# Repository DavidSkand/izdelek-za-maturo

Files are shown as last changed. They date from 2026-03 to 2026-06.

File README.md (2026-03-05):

# Projekt: Zaznavanje AprilTagov s kamero







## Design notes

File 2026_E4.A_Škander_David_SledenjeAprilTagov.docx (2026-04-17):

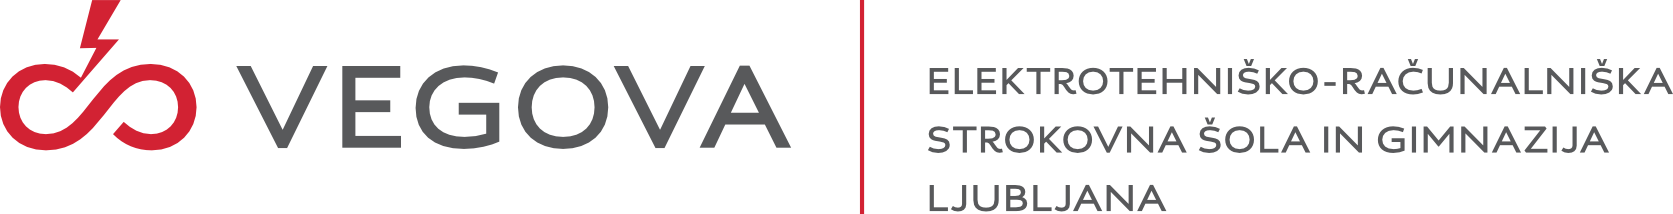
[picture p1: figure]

Lasersko sledenje AprilTag oznak

Strokovno poročilo

Mentor: David Zindović, prof. Avtor: David Škander, E 4. A

Ljubljana, april 2026

Povzetek

V sklopu strokovnega poročila je opisan razvoj laserskega sledilnega sistema, ki z uporabo računalniškega vida v realnem času zaznava oznake AprilTag in nanje usmeri laserski žarek. Sistem sestavljajo 3D-natisnjen nagibno-zasučni (pan-tilt) mehanizem, ki je bil v celoti zmodeliran v programu Fusion 360, dva servo motorja MG90S za krmiljenje gibanja, spletna kamera Logitech C920-C za zajem videa ter mikrokrmilnik Arduino Uno kot vmesnik med programsko in strojno opremo. Programski del sestavljata dve komponenti: skripta v jeziku Python, ki s pomočjo knjižnic OpenCV in pyapriltags zajema video, prepoznava oznake AprilTag, izračuna njihove koordinate v vidnem polju kamere in jih prek serijske povezave posreduje mikrokrmilniku, ter koda za Arduino, ki prejete koordinate pretvori v ustrezne kote servo motorjev z dodanim algoritmom glajenja premikov za tekoče sledenje. Projekt je bil uspešno realiziran in deluje v realnem času, med možnimi nadgradnjami pa sta izpostavljena implementacija PID-regulacije ter razširitev sistema na prepoznavanje obrazov in poljubnih premikajočih se objektov.

Ključne besede:

AprilTag, lasersko sledenje, nagibno-zasučni mehanizem, računalniški vid, OpenCV, Arduino Uno, servo motor, 3D tisk, Fusion 360, Python

Abstract

This report describes the development of a laser tracking system that uses computer vision to detect AprilTag markers in real time and direct a laser beam toward them. The system consists of a 3D-printed pan-tilt mechanism modelled in Fusion 360, two MG90S servo motors, a Logitech C920-C webcam and an Arduino Uno microcontroller. The software comprises a Python script using OpenCV and pyapriltags to detect markers and transmit their coordinates to the Arduino via serial communication, and Arduino code that converts the coordinates into servo angles with a smoothing algorithm for fluid motion. The project was successfully completed and operates in real time; potential upgrades include PID control and recognition of faces or arbitrary moving objects.

Keywords:

AprilTag, laser tracking, pan-tilt mechanism, computer vision, OpenCV, Arduino Uno, servo motor, 3D printing, Fusion 360, Python

## 1. UVOD

Misel o tem projektu se je rodila ob opazovanju sodobnih avtomatiziranih sistemov, kjer stroji z neverjetno hitrostjo opravljajo naloge, ki so za človeško oko skoraj neulovljive. Vedno me je navdušilo, kako lahko računalnik sploh vidi in razume, kaj se dogaja okoli njega in nato na podlagi teh podatkov krmili gibanje mehanizma. Izvedel sem, da se vrobotiki oznake AprilTag najpogosteje uporabljajo kot zanesljive referenčne točke za kalibracijo kamer in natančno določanje položaja v prostoru. Čeprav so na prvi pogled le nekakšni črno-beli kvadratki, nosijo v sebi podatke podobno kot QR-kode, vendar so zaradi manjše količine informacij bistveno hitrejše in bolj uporabne za sledenje.

Na podlagi tega sem se odločil, da to hitrost in natančnost uprizorim sam. Izdelal sem nagibno-zasučni laserski sistem (angl. pan-tilt), ki prek kamere in algoritmov prepozna oznako AprilTag v prostoru. Sistem nato podatke posreduje servo motorjema, ki ustrezno premakneta sklepe mehanizma in laserski žarek natančno usmerita v tarčo.

## 2. IZVEDBA PROJEKTA

### 2.1 Modeliranje in 3D tisk pan-tilt mehanizma

Ob začetku projekta nisem točno vedel, na kakšen način bi izvedel premikanje laserja, saj obstaja veliko različnih možnosti. Ugotovil sem, da se za takšne namene najpogosteje uporablja nagibno-zasučni (pan-tilt) sistem. Ta deluje tako, da zasučni del mehanizma (angl. pan) s pomočjo prvega servo motorja izvaja rotacijo okoli navpične osi, s čimer laserski žarek pomika po vodoravni ravnini (x-os). Nagibni del mehanizma (angl. tilt) pa z drugim motorjem omogoča rotacijo okoli vodoravne osi, kar žarek usmerja po navpični ravnini (y-os). Kljub temu da na spletu že obstaja veliko vnaprej pripravljenih 3D modelov, sem se odločil, da bom celoten sistem zmodeliral sam v programu Fusion 360. S tem sem želel pridobiti novo znanje modeliranja in se naučiti uporabljati omenjeni program.

Po analizi več primerov sem se odločil, da bom sistem ustvaril v treh različnih delih. Najprej sem začel z modeliranjem spodnjega dela, zasučnega (pan) mehanizma
(Slika 1). Začel sem z risanjem ravne podlage (oznaka 1), v katero sem v vsakem kotu postavil luknje za pritrdilne vijake (oznaka 2). Na sredino podlage sem nato zmodeliral namensko ohišje za prvi servo motor (oznaka 3), v katerem sem predvidel tudi ustrezen izrez za nemoten prehod priključnega kabla (oznaka 4).

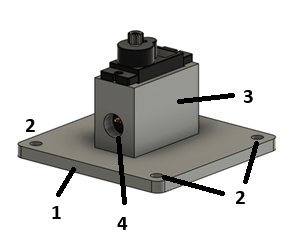
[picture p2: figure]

Slika 1: Model zasučnega mehanizma

Nato sem se lotil drugega dela, imenovanega U-kotnik, ki služi kot povezovalni člen med zasučnim in nagibnim (pan-tilt) mehanizmom (Slika 2). Ta model mi je vzel bistveno več časa in predstavljal večji izziv. Lotil sem se ga podobno kot prvega: najprej sem oblikoval ravno podlago (oznaka 1), nato pa ob straneh dodal vertikalni stojali (oznaka 2), ki podpirata zgornji del mehanizma. Na sredini podlage sem naredil glavno odprtino za pritrditev servo ročice na spodnji motor (oznaka 3), ob kateri so še manjše luknje za vijake, s katerimi se ročica čvrsto spoji s podlago. Na enem izmed stojal sem nato izdelal natančno priležno odprtino v obliki servo ročice (oznaka 4) ter dodal potrebne pritrdilne luknje. Tako se zgornji (tilt) servo motor prek ročice trdno privije neposredno na stojalo U-kotnika, s čimer sta oba mehanizma zanesljivo združena.

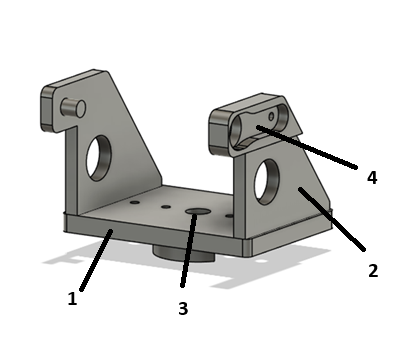
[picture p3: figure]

Slika 2: Model U-kotnika

Nazadnje sem zmodeliral še zgornji, nagibni (tilt) del sistema (Slika 3). Tudi pri tem delu sem začel z osnovno ploščo (oznaka 1), na kateri sem oblikoval ohišje za laser v obliki kvadra (oznaka 2). V ta kvader sem izrezal natančno odprtino, ki služi tesnemu prileganju in fiksiranju laserja (oznaka 3). Na spodnji strani plošče sem nato izdelal nosilna stebrička (oznaka 4) z odprtinami, ki sta prilagojeni za čvrsto pritrditev na zgornji servo motor. S tem sem zagotovil, da se celoten zgornji sklop skupaj z laserjem nemoteno nagiba okoli vodoravne osi.

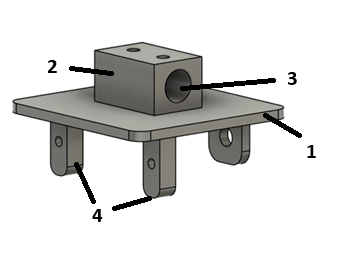
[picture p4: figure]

Slika 3: Model nagibnega mehanizma

In sedaj če sestavimo vse skupaj izgleda takole:

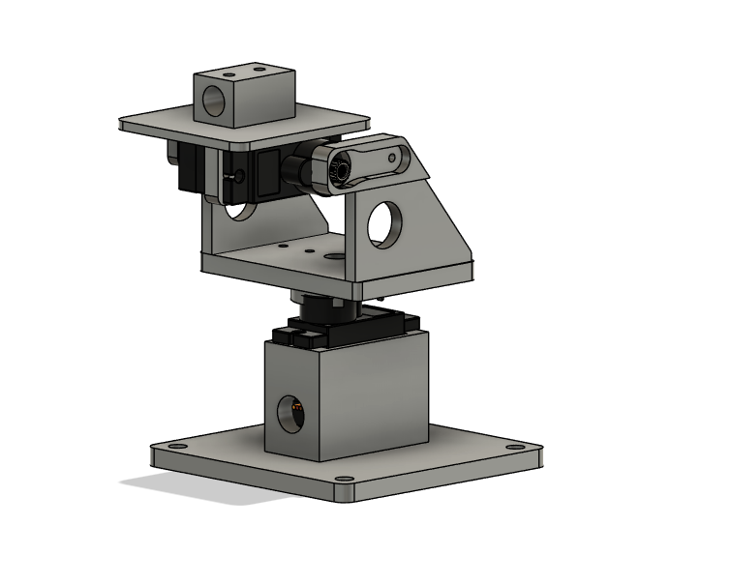
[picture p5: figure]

Slika 4: Sestavljen model nagibno-zasučnega sistema

### 2.2 Električne komponente in vezava

#### 2.2.1 Servo motor MG90S

Za premikanje obeh osi pan-tilt mehanizma sem izbral dva servo motorja MG90S. Odločitev za ta model je temeljila na njegovi sestavi, saj ima vgrajen kovinski prenos (zobnike), medtem ko ima osnovni model SG90 plastičnega. To motorjema omogoča doseganje večjega navora in zagotavlja večjo stabilnost pri prenašanju teže.

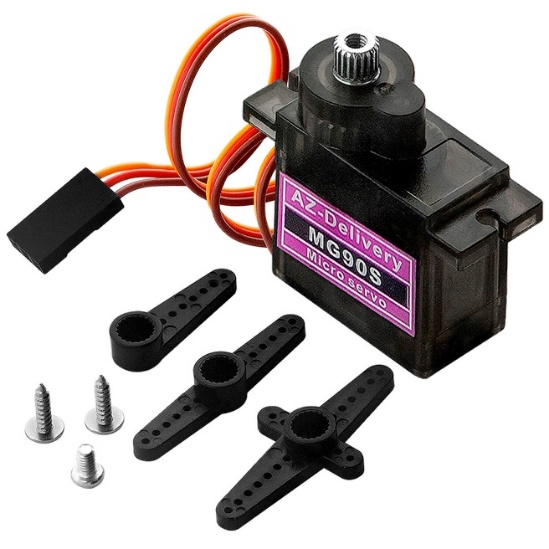
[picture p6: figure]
MG90S micro servo engine compatible with Arduino

Slika 5: Servo motor MG90S

#### 2.2.2 Mikrokrmilnik Arduino Uno

Za krmiljenje servo motorjev sem v sistem vključil mikrokrmilnik Arduino Uno, ki služi kot vmesnik med osebnim računalnikom in mehanskimi deli naprave. Ker servo motorji za natančno pozicioniranje potrebujejo ustrezen signal, sem za njihovo krmiljenje uporabil digitalne pine, ki podpirajo PWM (pulzno-širinsko modulacijo). Komunikacija z računalnikom in nalaganje programske opreme pa potekata neposredno preko USB vmesnika.

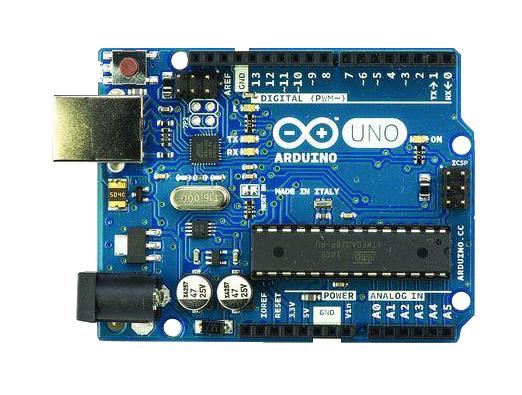
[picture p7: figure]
K010007 ARDUINO, Starter Kit, Arduino UNO, Projects Book | Farnell Slovenija

Slika 6: Mikrokrmilnik Arduino Uno

#### 2.2.3 Spletna kamera Logitech C920-C

Za zaznavanje oznak AprilTag sem uporabil spletno kamero Logitech C920-C. Kamera je fiksno nameščena tako, da ima neoviran pogled in s svojim zornim kotom v celoti pokriva območje, znotraj katerega se nahajajo tarče. Njena naloga je pošiljanje video signala na računalnik, kjer namenska skripta v jeziku Python video najprej zajame in pretvori v posamezne slike, jih obdela ter nato v njih s pomočjo algoritma poišče točne koordinate oznak.

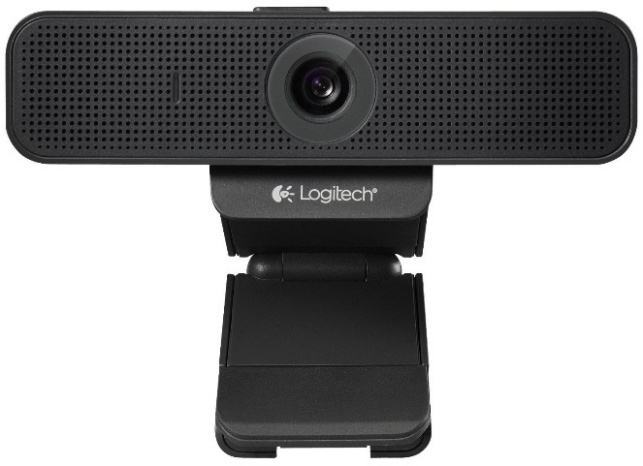
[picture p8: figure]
Logitech C920-C Webcam (Business Product) with 1080p HD Video Certified for Cisco Jabber : Amazon.ca: Electronics

Slika 7: Spletna kamera Logitech C920-C

#### 2.2.4 Laserska dioda

Kot vizualni indikator sledenja sem uporabil mini lasersko diodo z rdečim žarkom valovne dolžine 650 nm. Modul deluje pri napetosti 5 V z izhodno močjo 5 mW, kar pomeni, da se dobro vidi tudi pri dnevni svetlobi in hkrati spada v varen razred laserjev. Laserski modul je nameščen na zgornjem (tilt) delu 3D-natisnjenega mehanizma, tako da se žarek premika skupaj z motorjema in kaže na zaznano oznako.

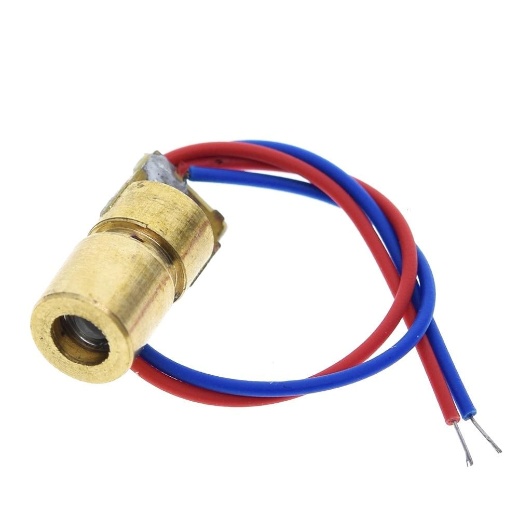
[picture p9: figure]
Adafruit 5mw Laser Diode 650nm 5mW Red Dot Laser Module – Focusable, 12x55mm, 5V Powered, Long Working Life For Positioning & Marking Adafruit Laser Diode 650nm

Slika 8: Modul laserja

#### 2.2.5 Arduino Sensor Shield v5 in napajanje

Za boljši izgled in preglednost sem uporabil razširitveno ploščo Arduino Sensor Shield v5. Ta omogoča preprosto povezovanje večjega števila komponent in modulov brez nepotrebnega prepletanja žic. Ker servo motorji ob delovanju porabijo precej električnega toka, bi njihovo neposredno napajanje preko mikrokrmilnika Arduino lahko povzročilo pregrevanje ali nestabilno delovanje. Da bi to preprečil, sistem napajam z zunanjim 5 V napajalnikom z izhodnim tokom 2 A. To zagotavlja dovolj moči za delovanje obeh motorjev in laserja, hkrati pa ščiti mikrokrmilnik pred preobremenitvijo.

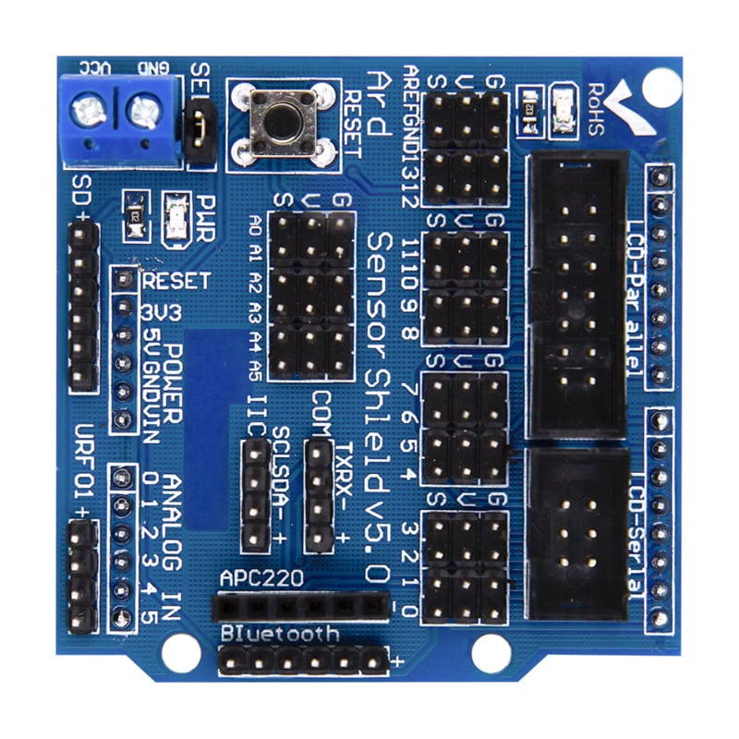
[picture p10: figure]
Sensor Shield v5.0 for Arduino UNO R3 - OTRONIC

Slika 9: Arduino Sensor Shield v5

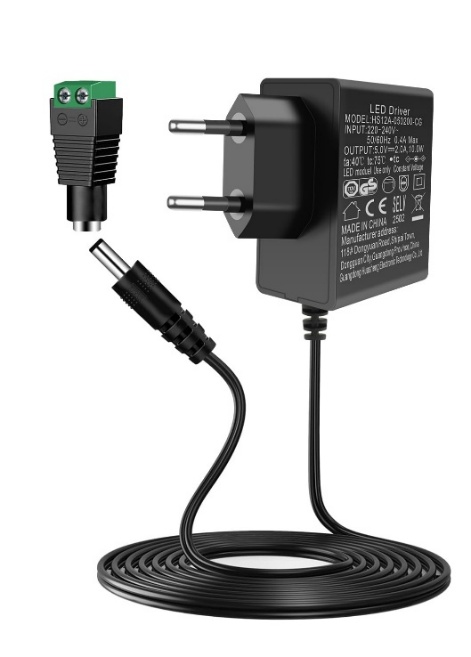
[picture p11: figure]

Slika 10: Napajalnik 5V 2A

#### 2.2.6 Električna vezava

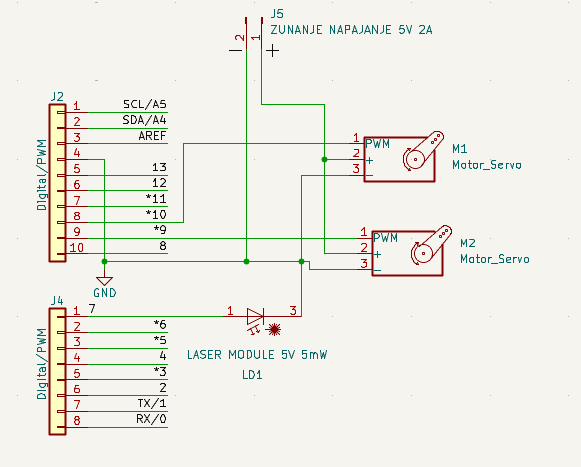
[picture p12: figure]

Slika 11: Električna vezava sistema

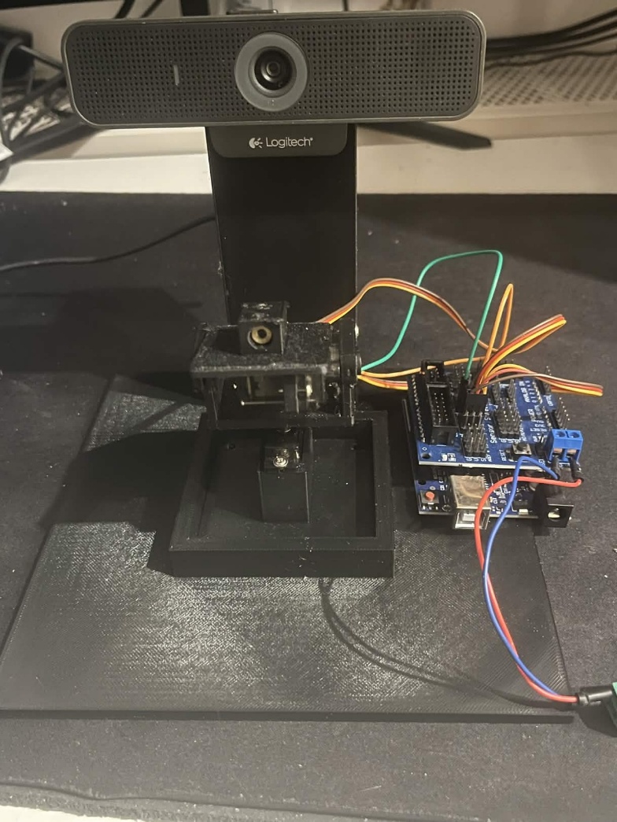
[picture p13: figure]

Slika 12: Sestavljen izdelek

### 2.3 Program

#### 2.3.1 Python skripta

Pri programskem delu sem se podrobneje poglobil v delovanje knjižnice OpenCV. Razvoj Python skripte sem izvedel postopoma: najprej sem implementiral zajem slike s kamere in zaznavanje oznak AprilTag. Zatem sem kodo nadgradil z algoritmom za izračun njihovih koordinat, v zadnjem koraku pa sem dodal še serijsko komunikacijo za pošiljanje teh podatkov mikrokrmilniku Arduino.

Slika 13: Izsek kode z uvozom knjižnic

Na začetku programske kode sem uvozil vse potrebne knjižnice (Slika 13). Za zajem in obdelavo videa sem uporabil knjižnico cv2 (OpenCV), za prepoznavanje oznak AprilTag pa namensko knjižnico pyapriltags. Knjižnico time sem potreboval za izračun in prikaz sličic na sekundo (FPS) ter za natančno časovno krmiljenje pošiljanja podatkov (omejitev na 33 Hz). Knjižnica serial pa skrbi za serijsko komunikacijo, ki sem jo uporabil za prenos izračunanih koordinat med Python kodo in mikrokrmilnikom Arduino.

Slika 14: Izsek kode za Inicializacijo kamere in serijske komunikacije.

V uvodnem delu programa (Slika 14) sem inicializiral zajem videa in komunikacijski vmesnik. S funkcijo cv2.VideoCapture(1) sem aktiviral spletno kamero. Nato sem s funkcijo serial.Serial iz knjižnice serial vzpostavil serijsko povezavo z mikrokrmilnikom Arduino preko vrat COM6. Hitrost prenosa sem nastavil na 115200 baudov, kar se mora ujemati z nastavitvami v Arduino kodi. Na koncu sem uporabil ukaz time.sleep(2), ki za dve sekundi začasno ustavi izvajanje skripte. Ta zamik je nujen za zanesljivo sinhronizacijo komunikacije med napravama, saj se ob odprtju serijskih vrat mikrokrmilnik samodejno ponovno zažene in potrebuje kratek čas, preden je pripravljen na sprejemanje podatkov.

Slika 15: Izsek kode z določitvijo spremenljivk in pogojev za pošiljanje.

V tem delu programske kode (Slika 15) sem definiral glavne parametre za obnašanje sistema. Z ukazom Detector() sem inicializiral iskalnik, ki na sliki prepozna oznake AprilTag. Začetni koordinati sta nastavljeni na 320 in 240, kar pri izbrani ločljivosti 480p (640x480) predstavlja natančno sredino vidnega polja kamere. Koordinate se mikrokrmilniku pošiljajo na vsake 0,03 sekunde, pri čemer se zadnje poslane vrednosti takoj shranijo v spremenljivki last_sent_x in last_sent_y. Na ta način program sproti preverja, za koliko pikslov se je oznaka dejansko premaknila. Če je ta premik manjši ali enak dvema piksloma, sistem novih koordinat ne pošlje.

Slika 16: Izsek kode za obdelavo slike in detekcijo oznak AprilTag.

V tem koraku (Slika 16) sem s funkcijo cv2.cvtColor zajeto sliko pretvoril v odtenke sive barve. Barvne slike so v knjižnici OpenCV standardno zapisane v formatu BGR, kar pomeni, da so sestavljene iz treh barvnih kanalov (modrega, zelenega in rdečega). S pretvorbo v sivinsko sliko sistem obdrži le en kanal, kar znatno zmanjša količino podatkov in pohitri obdelavo. Poleg tega knjižnica pyapriltags za svoje delovanje izrecno zahteva sivinsko sliko, saj barve pri prepoznavanju niso pomembne, temveč algoritem išče zgolj ostre kontraste med črnimi in belimi segmenti oznake. Primer pretvorbe je prikazan na spodnji sliki (Slika 16).

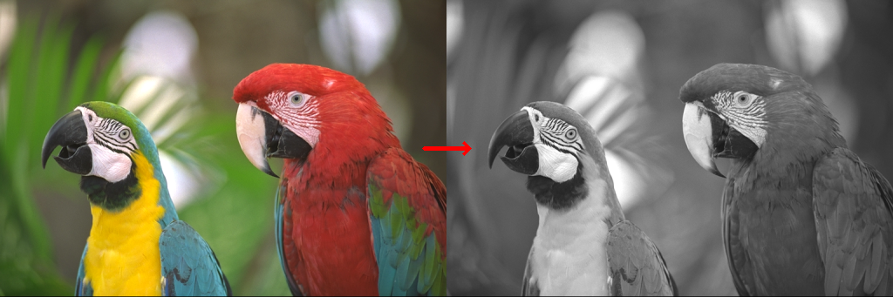
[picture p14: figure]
OpenCV.ImgProc.MiscImgTransform

Slika 17: Pretvorba iz BGR v sivinsko sliko

Vrstica kode tags = at_detector.detect(gray) izvede dejansko prepoznavanje in izolacijo oznak AprilTag na sliki. Detektor v tem koraku analizira sivinsko sliko in v spremenljivko tags shrani vse ugotovljene podatke o najdenih oznakah. Če kamera ne zazna nobene oznake, ostane ta seznam prazen. Ob uspešni detekciji pa program pridobi vse potrebne informacije (od identifikacijske številke (ID) do koordinat središča in vseh štirih oglišč oznake.

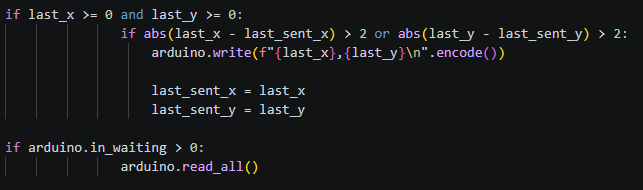
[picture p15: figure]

Slika 18: Izsek kode, ki preveri velikost premika značilke in pošlje podatke na Arduino.

Tukaj (Slika 18) se koordinate dejansko pošljejo na Arduino v formatu X,Y. Pred pošiljanjem se preveri veljavnost koordinat (last_x >= 0), ker če kamera ne zazna oznake vrednosti padejo na -1, kar bi povzročilo da laser skoči na napačno pozicijo. Na koncu se še počisti vhodni buffer Arduino krmilnika z read_all(), da se podatki ne kopičijo in povzročajo zamika.

Slika 19: Izsek kode, ki vizualno prikaže delovanje.

Za lažji pregled sem na okno kamere dodal vizualne indikatorje (Slika 19). S funkcijo cv2.rectangle program nariše moder okvir okoli zaznane značilke Apriltag, s funkcijo cv2.putText pa se pod njim izpiše njegov ID in koordinate. Tako lahko sproti vidim ali sistem pravilno zaznava oznako in kje na sliki se nahaja. Slika 20 pa prikazuje kako izgledae zaznavanje oznak in kako laser pokaže nanjo.

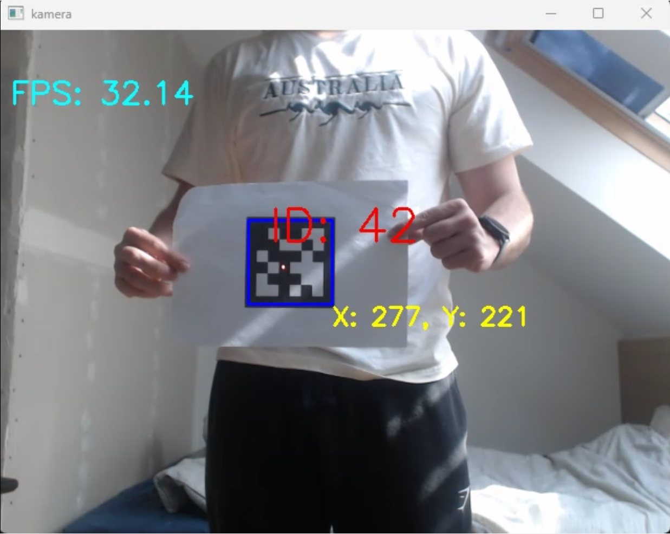
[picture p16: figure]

Slika 20: Prikaz zaznavanja oznak Apriltag

#### 2.3.2 Arduino koda

Naslednji sklop programske opreme predstavlja koda za mikrokrmilnik Arduino, ki deluje kot sprejemnik podatkov in skrbi za ustrezno premikanje zasučnega in nagibnega mehanizma.

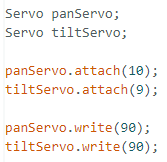
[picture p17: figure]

Slika 21: Izsek kode za deklaracijo in inicializacijo obeh servo motorjev.

Pred samo nastavitvijo pinov sem moral v kodi najprej deklarirati ustrezna objekta za oba motorja (s pomočjo vključene knjižnice Servo.h) (Slika 21). Nato sem s funkcijo attach() vsakemu objektu dodelil ustrezen priključni pin, pin 10 za zasučni in pin 9 za nagibni mehanizem. Oba izbrana pina podpirata pulzno-širinsko modulacijo (PWM), kar je nujno za krmiljenje servo motorjev. S klicem funkcije write(90) pa sem zagotovil, da se oba servota ob zagonu vedno premakneta na sredino, torej na 90 stopinj.

Slika 22: Izsek kode za preslikavo slikovnih koordinat (pikslov) v ciljne kote servo motorjev.

Ko Arduino prejme koordinate s strani računalnika, jih je potrebno pretvoriti v dejanske kote servo motorjev. To naredi funkcija floatMap() (Slika 22), ki X koordinato (0-640) pretvori v kot pan servoja, Y koordinato (0-480) pa v kot tilt servoja. Dodan je še pan_offset in tilt_offset za kalibracijo, ker laser ni nameščen točno na osi kamere.

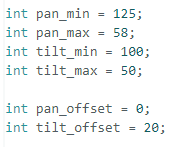
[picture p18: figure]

Slika 23: Izsek kode z definicijo mejnih kotov in začetnih odmikov za servo motorje

Na Sliki 23 spremenljivke določajo kalibracijo sistema. pan_min in pan_max določata kote servoja, ki ustrezata levemu in desnemu robu kamere — torej ko je oznaka na levem robu slike (X=0) se pan servo premakne na 125°, ko je na desnem robu (X=640) pa na 58°. Enako velja za tilt_min in tilt_max samo za Y os. tilt_offset = 20 pa je korekcija ker laser ni nameščen točno na osi kamere, kar povzroči da brez offseta laser ne kaže točno na oznako.

Slika 24: Izsek kode z algoritmom za bolj tekoče sledenje zaznani tarči.

Da pa se servo ne bi sunkovito premaknil neposredno na ciljno pozicijo, sem dodal glajenje (angl. smoothing) (Slika 24). Vrednost smoothing = 0.15 pomeni da se vsak korak premakne 15% proti cilju in ohrani 85% trenutne pozicije. Rezultat je gladko, postopno premikanje namesto nenadnih skokov, kar zmanjša obrabo servo motorjev in izboljša videz sledenja.

Slika 25: Izsek kode za varnostno omejevanje kotov

Servo motorji sicer omogočajo premik do 180 stopinj, vendar sem njun kot omejil med 10° in 170° s funkcijo constrain() (Slika 25). Da se motorja ne bi zadela ob fizične meje mehanizma in se tako poškodovala. Funkcija write() pa dejanski kot pošlje servoju kot PWM signal.

## 3. ZAKLJUČEK

Cilj projekta je bil izdelati laserski sledilni sistem, ki v realnem času zaznava oznake AprilTag in nanje usmeri laserski žarek prek nagibno-zasučnega mehanizma. Sistem je bil uspešno realiziran, kamera zaznava oznake, Python skripta izračuna njihove koordinate in jih posreduje mikrokrmilniku Arduino, ki ustrezno krmili oba servo motorja. Med izdelavo sem naletel na več praktičnih izzivov. Pri 3D tisku so bile mere nekaterih delov nepravilne, kar je povzročilo težave pri montaži: luknje za vijake so bile premajhne in nekateri deli so se zadevali ob stene ohišij, zato je bilo treba modele v programu Fusion 360 večkrat popraviti in dele natisniti znova. Zahtevna je bila tudi kalibracija sistema, saj laserski modul ni nameščen točno na osi kamere, kar povzroči sistematičen odmik žarka od središča zaznane oznake. Odmik sem delno odpravil z ročno nastavljenimi korekcijskimi vrednostmi v kodi, vendar popolne natančnosti ni mogoče doseči brez mehanske poravnave. Dodatno omejitev predstavlja tudi konstrukcijska zasnova, pri kateri celoten zgornji sklop sloni zgolj na prvem servo motorju brez dodatnih opor, kar pri hitrejših premikih zmanjša stabilnost sistema. Kljub tem izzivom projekt deluje v skladu z zastavljenimi cilji in predstavlja dobro osnovo za nadaljnji razvoj.

## 4. VIRI IN LITERATURA

OpenCV dokumentacija. 2026. OpenCV Tutorials. Dostopno prek: https://docs.opencv.org/4.13.0/d9/df8/tutorial_root.html (5. 1. 2026).

WillB97. 2026. pyapriltags. Dostopno prek:
https://github.com/WillB97/pyapriltags (18. 1. 2026).

AprilRobotics. 2026. apriltag. Dostopno prek:
https://github.com/AprilRobotics/apriltag (18. 1. 2026).

Arduino. 2026. Servo Motors with Arduino. Dostopno prek: https://docs.arduino.cc/learn/electronics/servo-motors/ (25. 1. 2026).

Bit-CCTV. 2025. What is Pan-Tilt. Dostopno prek:
https://www.bit-cctv.com/what-is-pan-tilt.html (22. 12. 2025).

GeeksforGeeks. 2026. OpenCV Python Tutorial. Dostopno prek: https://www.geeksforgeeks.org/python/opencv-python-tutorial/ (5. 1. 2026).

Alldatasheet. 2026. MG90S Datasheet. Dostopno prek: https://www.alldatasheet.com/datasheet-pdf/pdf/1132104/ETC2/MG90S.html (2. 2. 2026).

Arduino Forum. 2026. Arduino Sensor Shield v5. Dostopno prek: https://forum.arduino.cc/t/arduino-sensor-shield-v5-apc220-manual/223457 (15. 3. 2026).

Printables. 2025. 3D modeli. Dostopno prek:
https://www.printables.com/model/1069760-9g-servo-pan-tilt-system (22. 12. 2025).

Autodesk. 2025. Fusion 360. Dostopno prek:

https://www.autodesk.com/learn/ondemand/curated/introduction-to-fusion (22. 12. 2025).

IZJAVA O AVTORSTVU

Izjavljam, da je strokovno poročilo Lasersko sledenje AprilTag oznak v celoti moje avtorsko delo, ki sem ga izdelal samostojno s pomočjo navedene literature in pod vodstvom mentorja.

Datum: 17. 4. 2026

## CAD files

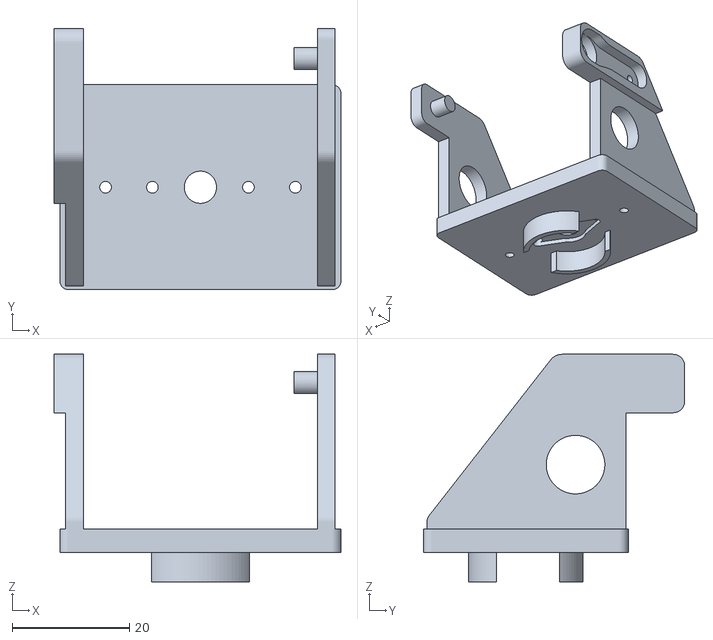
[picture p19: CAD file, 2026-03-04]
3d_design/ubracket.stl
49.0 x 44.6 x 38.8

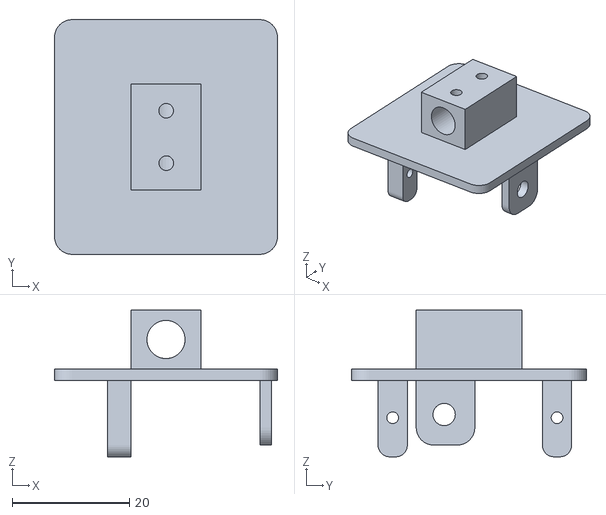
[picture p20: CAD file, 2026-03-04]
3d_design/tilt.stl
38.0 x 40.0 x 25.0

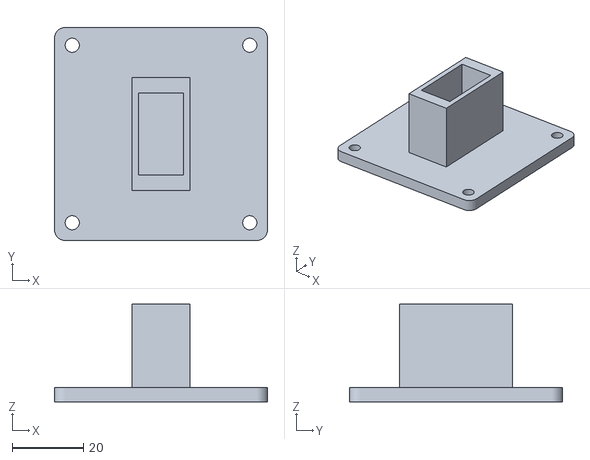
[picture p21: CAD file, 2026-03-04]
3d_design/base.stl
60.0 x 60.0 x 27.5

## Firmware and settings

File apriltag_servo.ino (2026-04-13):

#include <Servo.h>

Servo panServo;  // Pan os (X) na pinu 9
Servo tiltServo; // Tilt os (Y) na pinu 10

const int laserPin = 7;

// Spremenljivke za pozicijo
float currentPan = 90.0;
float currentTilt = 90.0;
float targetPan = 90.0;
float targetTilt = 90.0;

// Shranjevanje zadnjih koordinat za mrtvo območje
int last_x_pixel = 320;
int last_y_pixel = 240;

// Kalibracija - prilagodi glede na tvojo nastavitev
int pan_min = 125;   // Kot ko je X = 0
int pan_max = 58;    // Kot ko je X = 640
int tilt_min = 100; 
int tilt_max = 50;

// Mrtvo območje (Deadband) - število pikslov, ki jih ignoriramo
int deadband = 4; 

int pan_offset = 0;   // tune this: + moves laser right, - moves left
int tilt_offset = 20;  // tune this: + moves laser down, - moves up

// Glajenje premikanja (Smoothing)
float smoothing = 0.15; 
unsigned long lastSmoothUpdate = 0;
const unsigned long smoothInterval = 20; // Posodobitev na 20ms (50 Hz)

// Funkcija za preračun pikslov v kote
float floatMap(float x, float inMin, float inMax, float outMin, float outMax) {
  return (x - inMin) * (outMax - outMin) / (inMax - inMin) + outMin;
}

void setup() {
  Serial.begin(115200);
  Serial.setTimeout(5); // Hitra odzivnost serijske povezave
  
  panServo.attach(10);
  tiltServo.attach(9);
  
  // Postavi servomotorje na sredino ob zagonu
  panServo.write(90);
  tiltServo.write(90);

  pinMode(laserPin, OUTPUT);
  digitalWrite(laserPin, HIGH);
}

void loop() {
  // Preveri, če so prišli novi podatki iz računalnika
  if (Serial.available() > 0) {
    String data = Serial.readStringUntil('\n');
    data.trim();
    
    int commaIndex = data.indexOf(',');
    
    // Preveri, če je prejeti niz pravilen
    if (commaIndex > 0) {
      int x_pixel = data.substring(0, commaIndex).toInt();
      int y_pixel = data.substring(commaIndex + 1).toInt();

      // Mrtvo območje: posodobi cilj le, če je premik večji od deadband-a
      if (abs(x_pixel - last_x_pixel) > deadband || abs(y_pixel - last_y_pixel) > deadband) {
        
        // Izračunaj nove ciljne kote
        targetPan  = floatMap(x_pixel, 0, 640, pan_min, pan_max)  + pan_offset;
        targetTilt = floatMap(y_pixel, 0, 480, tilt_min, tilt_max) + tilt_offset;
        
        // Shrani zadnje piksle
        last_x_pixel = x_pixel;
        last_y_pixel = y_pixel;
      }
    }
  }

  // Glajenje in premikanje servomotorjev neodvisno od hitrosti Seriala
  unsigned long now = millis();
  if (now - lastSmoothUpdate >= smoothInterval) {
    lastSmoothUpdate = now;

    // Postopno premikanje proti cilju (Smoothing)
    currentPan = (targetPan * smoothing) + (currentPan * (1.0 - smoothing));
    currentTilt = (targetTilt * smoothing) + (currentTilt * (1.0 - smoothing));



    // Premik servomotorjev z varnostno omejitvijo
    panServo.write((int)constrain(currentPan, 10, 170));
    tiltServo.write((int)constrain(currentTilt, 10, 170));
  }
}

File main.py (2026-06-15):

import cv2
from pyapriltags import Detector
import time
import serial

camera = cv2.VideoCapture(0) 

at_detector = Detector()

start_time = time.time()  # Start the timer

arduino = serial.Serial(port='COM3',   baudrate=115200, timeout=.1)

last_x, last_y = 320, 240

last_seen = time.time()

timeout = 0.5 

last_sent_x = -1
last_sent_y = -1

time.sleep(2)  
last_send = 0
send_period = 0.03  # 33 Hz

#preveri če kamera deluje
if not camera.isOpened():  
    print('cannot open camera')
    exit()


while(camera.isOpened()):
    ret, frame = camera.read()       #pridobi ret, Width,Height
    if ret == False:    
        print('something went wrong')
        break
      

    if ret == True:
        gray = cv2.cvtColor(frame, cv2.COLOR_BGR2GRAY)  
        tags = at_detector.detect(gray)   #lista tagsx
        now = time.time()

        if len(tags) > 0:
            # choose one tag (first one)
            tag = tags[0]
            center = tag.center
            last_x, last_y = int(center[0]), int(center[1])


        #vzame listo in kliče vsak tag posebaj
        for tag in tags: 
            center = tag.center
            tagid = tag.tag_id
            width, height = 80, 80
            top_left = (int(center[0] - width/2), int(center[1] - height/2))
            bottom_right = (int(center[0] + width/2), int(center[1] + height/2))
            cv2.rectangle(frame, top_left,  bottom_right, (255,0,0), 2)
            text_position = (int(center[0] - width / 4), int(center[1] - height / 4))
            cv2.putText(frame, f"ID: {tagid}", text_position, cv2.FONT_HERSHEY_SIMPLEX, 1.5, (0,0,255), 2 )
            xy_position = f"X: {int(center[0])}, Y: {int(center[1])}"
            cv2.putText(frame, xy_position, (bottom_right[0], bottom_right[1] + 20),  cv2.FONT_HERSHEY_SIMPLEX, 0.8, (0, 255, 255), 2)

        now2 = time.time()
        if now2 - last_send >= send_period:
           
           if last_x >= 0 and last_y >= 0:
               if abs(last_x - last_sent_x) > 2 or abs(last_y - last_sent_y) > 2:
                   arduino.write(f"{last_x},{last_y}\n".encode())
                   
                   last_sent_x = last_x
                   last_sent_y = last_y

           # Keep the buffer clear but don't print anything
           if arduino.in_waiting > 0:
               arduino.read_all() 
            
           last_send = now2


        # Izračun FPS
        loop_time = time.time() - start_time
        if loop_time > 0:
            fps = 1 / loop_time
            cv2.putText(frame, f"FPS: {fps:.2f}", (10, 70), cv2.FONT_HERSHEY_SIMPLEX, 1, (255, 255, 0), 2)
        
        start_time = time.time()


        cv2.imshow('kamera', frame)
        
        if cv2.waitKey(1) & 0xFF == ord('q'):
            break

        
camera.release()
cv2.destroyAllWindows()
arduino.close()  

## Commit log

2026-02-04 Integrate Arduino communication and change camera index
    Added serial communication with Arduino and updated camera index.
2026-02-05 Update Arduino port and improve camera handling
2026-03-04 Refactor servo control logic and improve readability
2026-03-04 Refactor camera processing and improve FPS calculation
2026-03-04 Enhance servo control with target coordinates and smoothing
    Added target coordinates and smoothing for servo control.
2026-03-05 Refactor servo variables and implement smoothing
    Refactor servo control logic and improve variable naming.
2026-03-05 Enhance coordinate sending and buffer management
    Added validation for coordinates before sending to Arduino and improved buffer handling.
2026-04-13 Adjust servo pin assignments and add laser control
2026-06-15 Improve coordinate validation before sending to Arduino
    Refactor coordinate handling to prevent sending invalid coordinates.
    [main.py]
2026-06-16 Add mac version for camera and Arduino integration
